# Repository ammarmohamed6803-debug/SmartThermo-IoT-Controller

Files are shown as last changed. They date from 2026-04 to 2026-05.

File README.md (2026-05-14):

# SmartThermo: IoT Environmental Controller 🌡️⚙️

An automated, closed-loop climate regulation and telemetry logging system built with an ESP32. This project reverse-engineers stateful AC IR protocols to maintain strict temperature tolerances while logging real-time data to the cloud.

## Features
* **Real-Time Edge Sensing:** Uses a DHT22 sensor for high-fidelity temperature and humidity tracking.
* **Algorithmic IR Control:** Generates mathematical 64-bit Gree/Sharp IR protocols on the fly to eliminate signal jitter and reliably control the AC unit.
* **Closed-Loop Actuation:** Automatically adjusts the AC state to maintain a strict ±0.5°C tolerance of the user's setpoint.
* **Cloud Telemetry Logging:** Connects via Wi-Fi to POST JSON payload data (Temp, Hum, AC State, Setpoint) to a custom Google Apps Script webhook, logging chronologically in Google Sheets.
* **Tactile HMI & Alerts:** Features an I2C LCD for live telemetry, manual override buttons, and a non-blocking audiovisual alarm system for out-of-range states.

## Hardware Components
* ESP32 Development Board
* DHT22 Temperature & Humidity Sensor
* 38kHz IR Transmitter LED (driven by 2N2222 NPN Transistor)
* 16x2 I2C LCD Display
* Active Buzzer & Status LEDs (Red/Green)
* Tactile Push Buttons

## System Architecture 


## Circuit Schematic


## 3D Enclosure Design


## Libraries Used
* `IRremoteESP8266` (For Gree/TECO/Haier protocol generation)
* `DHT sensor library`
* `LiquidCrystal_I2C`
* `WiFi.h` & `HTTPClient.h`

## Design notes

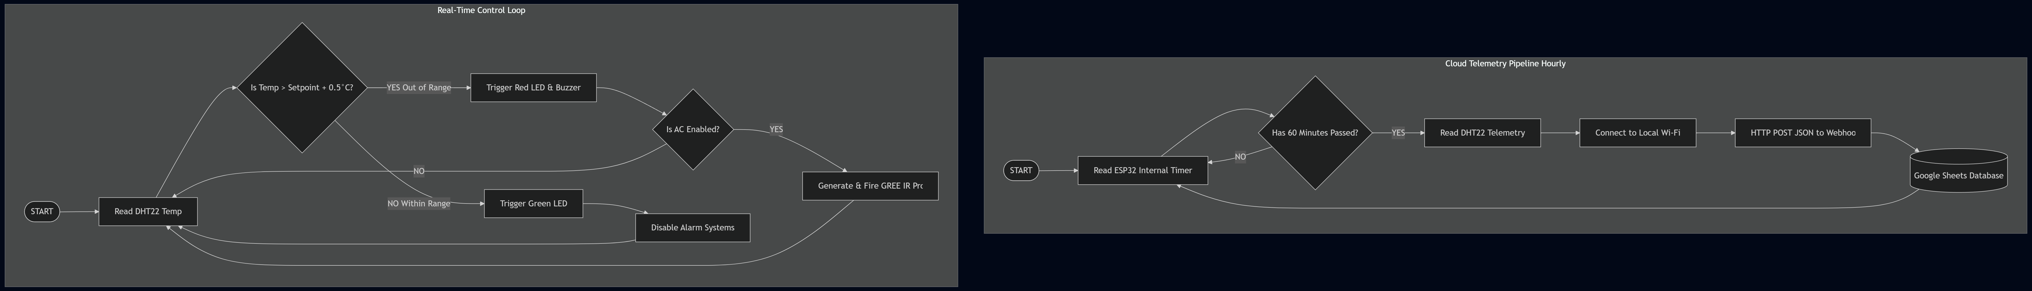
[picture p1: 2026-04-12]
flowchart.png

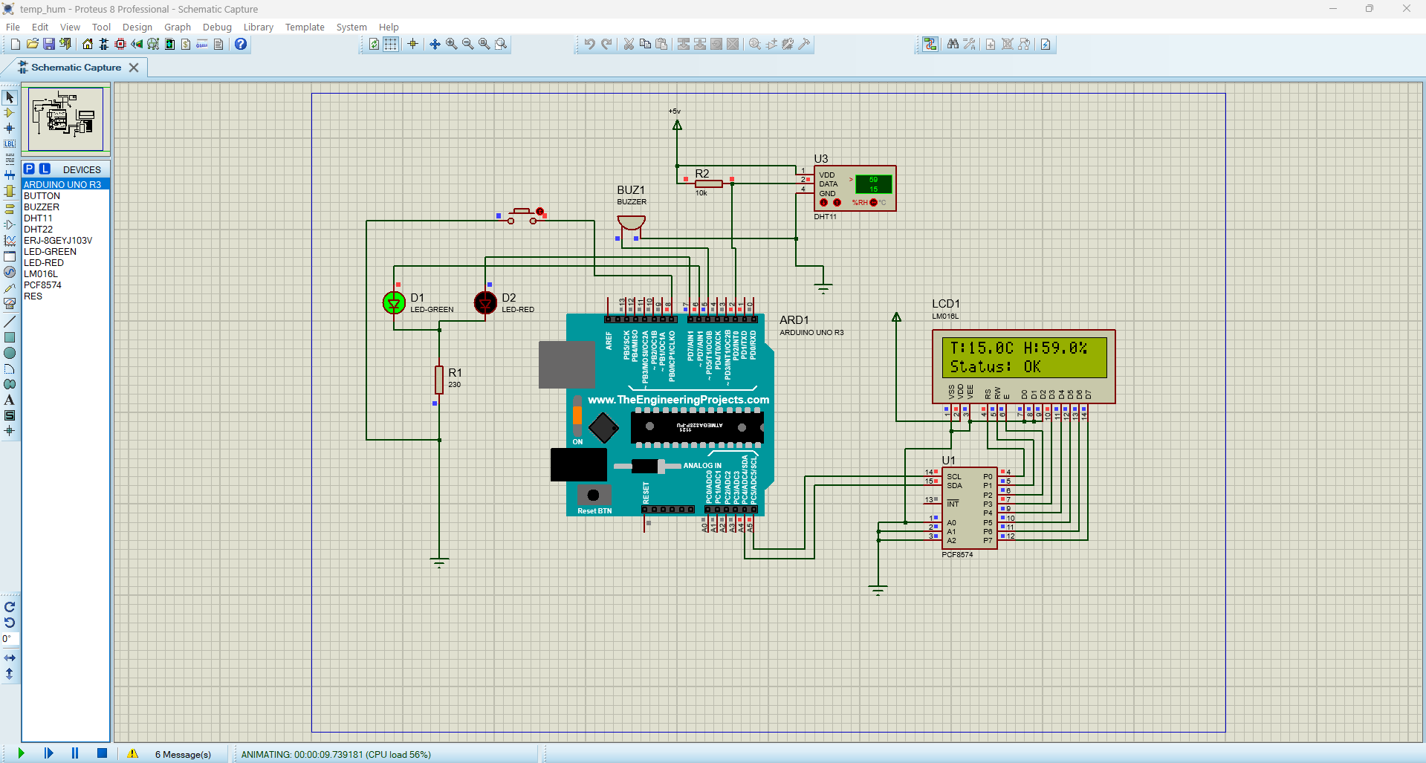
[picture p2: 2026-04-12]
basic circuit.png

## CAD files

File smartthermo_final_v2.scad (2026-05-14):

// ============================================================
//  SmartThermo Enclosure — FINAL v2
//  For: ESP32 + 16x2 LCD I2C + DHT22-MOD + IR LED + LEDs
//       + Buzzer + 3 Buttons + 400pt Breadboard + Jumper Wires
// ============================================================
//  Print settings: 0.2mm layer, 20% infill, no supports needed
//  Material: PLA or PETG
// ============================================================
//  v2 fixes:
//    - USB hole: fixed translate Y (was not reaching inner face)
//    - Wall mount keyholes: same fix + repositioned near top
//    - keyhole_slot depth increased to wall+4 (cuts fully through)
//    - Box + Lid combined in ONE STL file
// ============================================================

/* [Main Dimensions] */
wall        = 2.5;
corner_r    = 3;

inner_w     = 100;
inner_d     = 90;
inner_h     = 70;

outer_w     = inner_w + 2*wall;   // 105mm
outer_d     = inner_d + 2*wall;   // 95mm
outer_h     = inner_h + 2*wall;   // 75mm

/* [LCD Cutout — 16x2 I2C] */
lcd_view_w  = 65;
lcd_view_h  = 15;
lcd_pcb_w   = 80;
lcd_pcb_h   = 36;
lcd_x       = 0;
lcd_z       = 12;

/* [Buttons — 6mm panel-mount, 7mm holes] */
btn_dia     = 7;
btn_spacing = 14;
btn_x_start = 10;
btn_z_pos   = -20;

/* [LEDs — 5mm] */
led_dia     = 5.2;
led_spacing = 10;
led_x_off   = -20;
led_z_off   = -20;

/* [IR LED] */
ir_dia      = 5.2;
ir_x        = -38;
ir_z        = -20;

/* [DHT22 — through-hole, insert from inside] */
dht_cut_w   = 20;
dht_cut_h   = 25;
dht_z_off   = 5;

/* [Buzzer — on LID] */
buzz_dia    = 2.0;
buzz_count  = 7;
buzz_r      = 6;
buzz_x      = 25;
buzz_y      = 10;

/* [USB — back face] */
usb_w       = 14;
usb_h       = 8;
usb_z       = -25;

/* [Mounting Posts] */
post_hole   = 2.5;

/* [Lid] */
lid_h       = 2.5;

/* [Wall Mount — keyhole slots on back, near top] */
mount_slot_w  = 8;
mount_slot_h  = 14;
mount_spacing = 60;
// Near top of back face so box hangs below the screws
mount_z       = outer_h - lid_h - 18;   // ~54mm from bottom

// ── Helper: rounded box ──────────────────────────────────
module rounded_box(w, d, h, r) {
    hull() {
        for (x = [-w/2+r, w/2-r])
            for (y = [-d/2+r, d/2-r])
                translate([x, y, 0])
                    cylinder(h=h, r=r, $fn=40);
    }
}

// ── Rounded slot helper ──────────────────────────────────
module rounded_slot(w, h, depth) {
    hull() {
        for (y = [-h/2 + w/2, h/2 - w/2])
            translate([0, y, 0])
                cylinder(d=w, h=depth, $fn=20);
    }
}

// ── Rounded rectangular cutout ───────────────────────────
module rounded_lcd_cutout(w, h, depth) {
    r = 1.5;
    hull() {
        for (x = [-w/2+r, w/2-r])
            for (y = [-h/2+r, h/2-r])
                translate([x, y, 0])
                    cylinder(r=r, h=depth, $fn=20);
    }
}

// ── Keyhole wall mount slot ──────────────────────────────
// depth = wall+4 so it cuts fully from inner to outer face
module keyhole_slot(depth) {
    // Large circle at top — screw HEAD passes through to hang
    translate([0, mount_slot_h/2 - mount_slot_w/2, 0])
        cylinder(d=mount_slot_w, h=depth, $fn=30);
    // Vertical slot — box slides DOWN onto screw shaft
    translate([-mount_slot_w/4, -mount_slot_h/2, 0])
        cube([mount_slot_w/2, mount_slot_h, depth]);
    // Small circle at bottom — grips screw shaft snugly
    translate([0, -mount_slot_h/2, 0])
        cylinder(d=mount_slot_w/2, h=depth, $fn=20);
}

// ── MAIN BOX ─────────────────────────────────────────────
module main_box() {
    difference() {

        // Outer shell
        rounded_box(outer_w, outer_d, outer_h - lid_h, corner_r);

        // Inner cavity
        translate([0, 0, wall])
            rounded_box(inner_w, inner_d, outer_h, corner_r - wall/2);

        // ════════════════════════════════════════════════
        // FRONT FACE cutouts
        // ════════════════════════════════════════════════

        // LCD viewing window
        translate([lcd_x, -outer_d/2 - 1, outer_h/2 + lcd_z])
            rotate([-90, 0, 0])
                rounded_lcd_cutout(lcd_view_w, lcd_view_h, wall + 2);

        // LCD PCB slot (recessed from inside)
        translate([lcd_x, -outer_d/2 + wall - 1, outer_h/2 + lcd_z])
            rotate([-90, 0, 0])
                rounded_lcd_cutout(lcd_pcb_w + 1, lcd_pcb_h + 1, 2);

        // Green LED hole
        translate([led_x_off - led_spacing/2, -outer_d/2 - 1, outer_h/2 + led_z_off])
            rotate([-90, 0, 0])
                cylinder(d=led_dia, h=wall+2, $fn=30);

        // Red LED hole
        translate([led_x_off + led_spacing/2, -outer_d/2 - 1, outer_h/2 + led_z_off])
            rotate([-90, 0, 0])
                cylinder(d=led_dia, h=wall+2, $fn=30);

        // LED label indents
        translate([led_x_off - led_spacing/2, -outer_d/2 - 0.1, outer_h/2 + led_z_off + 6])
            rotate([-90, 0, 0])
                cylinder(d=2, h=0.8, $fn=20);
        translate([led_x_off + led_spacing/2, -outer_d/2 - 0.1, outer_h/2 + led_z_off + 6])
            rotate([-90, 0, 0])
                cylinder(d=2, h=0.8, $fn=20);

        // IR LED hole + cone
        translate([ir_x, -outer_d/2 - 1, outer_h/2 + ir_z])
            rotate([-90, 0, 0])
                cylinder(d=ir_dia, h=wall+2, $fn=30);
        translate([ir_x, -outer_d/2 - 0.1, outer_h/2 + ir_z])
            rotate([-90, 0, 0])
                cylinder(d1=ir_dia, d2=ir_dia+3, h=wall+0.2, $fn=30);

        // Button holes — 7mm for 6mm panel-mount buttons
        for (i = [0, 1, 2]) {
            translate([btn_x_start + i * btn_spacing, -outer_d/2 - 1, outer_h/2 + btn_z_pos])
                rotate([-90, 0, 0])
                    cylinder(d=btn_dia, h=wall+2, $fn=30);
        }

        // Button labels: DN / PWR / UP
        translate([btn_x_start, -outer_d/2 - 0.1, outer_h/2 + btn_z_pos + 7])
            rotate([90, 0, 0]) linear_extrude(0.8)
                text("DN", size=3, halign="center", valign="center",
                     font="Liberation Sans:style=Bold");
        translate([btn_x_start + btn_spacing, -outer_d/2 - 0.1, outer_h/2 + btn_z_pos + 7])
            rotate([90, 0, 0]) linear_extrude(0.8)
                text("PWR", size=2.5, halign="center", valign="center",
                     font="Liberation Sans:style=Bold");
        translate([btn_x_start + 2*btn_spacing, -outer_d/2 - 0.1, outer_h/2 + btn_z_pos + 7])
            rotate([90, 0, 0]) linear_extrude(0.8)
                text("UP", size=3, halign="center", valign="center",
                     font="Liberation Sans:style=Bold");

        // ════════════════════════════════════════════════
        // RIGHT SIDE — DHT22 through-hole
        // Starts 1mm before inner wall → cuts fully through
        // ════════════════════════════════════════════════
        translate([inner_w/2 - 1, 0, outer_h/2 + dht_z_off])
            rotate([0, 90, 0])
                rounded_lcd_cutout(dht_cut_w, dht_cut_h, wall + 4);

        // ════════════════════════════════════════════════
        // BACK FACE — USB port
        // FIXED: translate Y = inner_d/2 - 1 (starts before inner face)
        //        depth = wall + 4  (cuts fully through to outside)
        // ════════════════════════════════════════════════
        translate([0, inner_d/2 - 1, outer_h/2 + usb_z])
            rotate([90, 0, 0])
                rounded_slot(usb_w, usb_h, wall + 4);

        // ════════════════════════════════════════════════
        // BACK FACE — Wall mount keyhole slots
        // FIXED: translate Y = inner_d/2 - 1 (starts before inner face)
        //        depth = wall + 4 passed into module
        //        mount_z near top of box for proper wall hang
        // ════════════════════════════════════════════════
        for (x = [-mount_spacing/2, mount_spacing/2])
            translate([x, inner_d/2 - 1, mount_z])
                rotate([90, 0, 0])
                    keyhole_slot(wall + 4);

        // ════════════════════════════════════════════════
        // BOTTOM — ventilation slots
        // ════════════════════════════════════════════════
        for (i = [-3:3]) {
            translate([i * 12, 0, -1])
                rounded_slot(3, 40, wall + 2);
        }
    }

    // ── Screw posts for lid ──────────────────────────────
    screw_inset = 6;
    for (x = [-inner_w/2 + screw_inset, inner_w/2 - screw_inset])
        for (y = [-inner_d/2 + screw_inset, inner_d/2 - screw_inset])
            translate([x, y, wall])
                difference() {
                    cylinder(d=6, h=outer_h - lid_h - wall, $fn=30);
                    translate([0, 0, outer_h - lid_h - wall - 8])
                        cylinder(d=post_hole, h=10, $fn=20);
                }
}

// ── LID ──────────────────────────────────────────────────
module lid() {
    difference() {
        rounded_box(outer_w, outer_d, lid_h, corner_r);
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

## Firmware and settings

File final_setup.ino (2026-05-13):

/*
 * ============================================================
 * SmartThermo Phase 4 — 3-button final
 * ESP32 + DHT22 + Gree AC (IR) + I2C LCD + Wi-Fi Logging
 * ============================================================
 * v4.2 changes:
 *   - FIXED: IR transmission now suspends log task during send
 *           (prevents Wi-Fi/FreeRTOS timing disruption)
 *   - Reverted to single IR send (double-send was unreliable)
 *   - 3 buttons: UP, DOWN, POWER
 *   - UP/DOWN auto-sends new setpoint after 2s wait
 *   - UP long-press (2s) toggles MANUAL / AUTO mode
 *   - POWER toggles AC ON/OFF
 *   - Alarm fires when OUT of range
 *   - HTTP logging on Core 0 (non-blocking)
 * ============================================================
 * MODE 1: Manual — UP/DOWN sets AC temp directly
 * MODE 2: Auto  — UP/DOWN sets target ROOM temp
 * ──────────────────────────────────────────────────────────────
 * UP short      : setpoint +1  (auto-sends after 2s if AC on)
 * UP long (2s)  : toggle MANUAL / AUTO mode
 * DOWN short    : setpoint -1  (auto-sends after 2s if AC on)
 * POWER short   : toggle AC ON / OFF
 * ============================================================
 * >>>  CHANGE roomName PER UNIT BEFORE UPLOADING  
 * ============================================================
 */

#include <Arduino.h>
#include <Wire.h>
#include <LiquidCrystal_I2C.h>
#include <IRremoteESP8266.h>
#include <ir_Gree.h>
#include <DHT.h>
#include <WiFi.h>
#include <HTTPClient.h>
#include "soc/soc.h"
#include "soc/rtc_cntl_reg.h"

// ══════════════════════════════════════════════════════════════
//  CHANGE THIS PER ROOM — must match the Google Sheet tab name
// ══════════════════════════════════════════════════════════════
const char* roomName = "Filling Room";

// ── Wi-Fi & Google Sheets config ─────────────────────────────
const char* ssid      = "SparkeLabs_2.4GHz";
const char* password  = "12345678";
const char* scriptUrl = "https://script.google.com/macros/s/AKfycby3Sph_hCZV9bX5cS6v5fkehoYulXwKRZOLm6wEMfRHKZ4dpHyjm0AnLq1JRopFkwZ4/exec";

// ── Pin config ───────────────────────────────────────────────
#define IR_LED_PIN      4
#define DHT_PIN         14
#define BTN_UP_PIN      12
#define BTN_DOWN_PIN    32
#define BTN_POWER_PIN   33
#define RED_LED_PIN     25
#define GREEN_LED_PIN   26
#define BUZZER_PIN      27

// ── Settings ─────────────────────────────────────────────────
#define TEMP_MIN        16
#define TEMP_MAX        30
#define TEMP_DEFAULT    21
#define AUTO_OFFSET     2

// ── Alarm range (OUT of these = alarm) ───────────────────────
#define ALARM_TEMP_LOW   18.0
#define ALARM_TEMP_HIGH  30.0
#define ALARM_HUM_LOW    30.0
#define ALARM_HUM_HIGH   90.0

// ── Timing ───────────────────────────────────────────────────
#define DHT_INTERVAL_MS       2000
#define LONG_PRESS_MS         2000
#define BUZZER_ON_MS          150
#define BUZZER_OFF_MS         150
#define LOG_INTERVAL_MS       3600000UL
#define AUTO_RESEND_MS        900000UL
#define LOG_DEFER_MS          5000
#define DEBOUNCE_MS           50
#define SETPOINT_SEND_DELAY   2000

// ── Modes ────────────────────────────────────────────────────
#define MODE_MANUAL  0
#define MODE_AUTO    1

// ── Objects ──────────────────────────────────────────────────
DHT dht(DHT_PIN, DHT22);
LiquidCrystal_I2C lcd(0x27, 16, 2);
IRGreeAC ac(IR_LED_PIN);

// ── State ────────────────────────────────────────────────────
float currentTemp     = 0.0;
float currentHumidity = 0.0;
bool  sensorReady     = false;
bool  acOn            = false;
bool  alertActive     = false;
bool  buzzerState     = false;
int   setpoint        = TEMP_DEFAULT;
int   currentMode     = MODE_MANUAL;

unsigned long lastAutoSend = 0;
bool autoHasSentOnce = false;

TaskHandle_t   logTaskHandle = NULL;
volatile bool  logRequested  = false;
bool pendingLog = false;

bool pendingSetpointSend = false;
unsigned long lastSetpointChange = 0;

// ── Timing Variables ─────────────────────────────────────────
unsigned long lastDHTRead         = 0;
unsigned long lastBuzzerTime      = 0;
unsigned long lastLogTime         = 0;
unsigned long lastInteractionTime = 0;

// ── Button state ─────────────────────────────────────────────
bool lastUpState    = HIGH;
bool lastDownState  = HIGH;
bool lastPowerState = HIGH;
unsigned long upPressTime = 0;
bool upHeld = false;

unsigned long lastUpDebounce    = 0;
unsigned long lastDownDebounce  = 0;
unsigned long lastPowerDebounce = 0;

// ── HTTP runs on Core 0 (non-blocking) ───────────────────────
void logTask(void *parameter) {
  for (;;) {
    if (logRequested) {
      logRequested = false;

      if (WiFi.status() == WL_CONNECTED && sensorReady) {
        Serial.println("[WIFI] Connecting to Google...");
        HTTPClient http;
        http.begin(scriptUrl);
        http.addHeader("Content-Type", "application/json");
        http.setTimeout(5000);

        String modeStr = (currentMode == MODE_AUTO) ? "AUTO" : "MANUAL";
        String payload = "{\"room\":\"" + String(roomName) + "\"" +
                         ",\"temp\":" + String(currentTemp, 1) +
                         ",\"hum\":" + String(currentHumidity, 1) +
                         ",\"acState\":\"" + (acOn ? "ON" : "OFF") + "\"" +
                         ",\"setpoint\":" + String(setpoint) +
                         ",\"mode\":\"" + modeStr + "\"}";

        Serial.println("[WIFI] Sending: " + payload);
        int httpResponseCode = http.POST(payload);

        if (httpResponseCode > 0) {
          Serial.print("[WIFI] Success! HTTP Code: ");
          Serial.println(httpResponseCode);
        } else {
          Serial.print("[WIFI] Error sending POST: ");
          Serial.println(httpResponseCode);
        }
        http.end();
      } else if (WiFi.status() != WL_CONNECTED) {
        Serial.println("[WIFI] Not connected. Skipping log.");
      }
    }
    vTaskDelay(100 / portTICK_PERIOD_MS);
  }
}

// ── IR Helper Functions ──────────────────────────────────────
// FIX: suspend log task during IR send to prevent timing disruption.
// FreeRTOS + Wi-Fi can interfere with the 38kHz IR carrier.
void sendACCommand(int acTemp) {
  if (acTemp < TEMP_MIN) acTemp = TEMP_MIN;
  if (acTemp > TEMP_MAX) acTemp = TEMP_MAX;

  // Pause the log task so HTTP/Wi-Fi doesn't disrupt IR timing
  if (logTaskHandle != NULL) vTaskSuspend(logTaskHandle);
  noInterrupts();   // protect IR carrier timing

  ac.setPower(true);
  ac.setMode(kGreeCool);
  ac.setFan(kGreeFanAuto);
  ac.setTemp(acTemp);
  ac.send();

  interrupts();
  if (logTaskHandle != NULL) vTaskResume(logTaskHandle);

  Serial.print("[IR] AC ON -> ");
  Serial.print(acTemp);
  Serial.println("C");
}

void sendACOff() {
  if (logTaskHandle != NULL) vTaskSuspend(logTaskHandle);
  noInterrupts();

  ac.setPower(false);
  ac.send();

  interrupts();
  if (logTaskHandle != NULL) vTaskResume(logTaskHandle);

  Serial.println("[IR] AC OFF");
}

// ── LCD update ───────────────────────────────────────────────
void updateLCD() {
  lcd.clear();

  lcd.setCursor(0, 0);
  if (sensorReady) {
    lcd.print("T:");
    lcd.print(currentTemp, 1);
    lcd.print("C H:");
    lcd.print((int)currentHumidity);
    lcd.print("%");
  } else {
    lcd.print("T:---  H:---");
  }

  lcd.setCursor(0, 1);
  if (currentMode == MODE_MANUAL) {
    if (acOn) {
      lcd.print("AC:ON S:");
      lcd.print(setpoint);
      lcd.print("C");
    } else {
      lcd.print("AC:OFF S:");
      lcd.print(setpoint);
      lcd.print("C");
    }
  } else {
    if (acOn) {
      lcd.print("AUTO T:");
      lcd.print(setpoint);
      lcd.print("C [ON]");
    } else {
      lcd.print("AUTO T:");
      lcd.print(setpoint);
      lcd.print("C[OFF]");
    }
  }
}

// ── Alert indicators ─────────────────────────────────────────
void updateAlert(bool active) {
  alertActive = active;
  if (!active) {
    digitalWrite(GREEN_LED_PIN, HIGH);
    digitalWrite(RED_LED_PIN,   LOW);
    digitalWrite(BUZZER_PIN,    LOW);
    buzzerState = false;
  } else {
    digitalWrite(GREEN_LED_PIN, LOW);
    digitalWrite(RED_LED_PIN,   HIGH);
  }
}

// ── Buzzer non-blocking blink ────────────────────────────────
void handleBuzzer() {
  if (!alertActive) return;
  unsigned long now = millis();
  if (buzzerState && now - lastBuzzerTime >= BUZZER_ON_MS) {
    buzzerState = false;
    digitalWrite(BUZZER_PIN, LOW);
    lastBuzzerTime = now;
  } else if (!buzzerState && now - lastBuzzerTime >= BUZZER_OFF_MS) {
    buzzerState = true;
    digitalWrite(BUZZER_PIN, HIGH);
    lastBuzzerTime = now;
  }
}

// ── Beep helpers ─────────────────────────────────────────────
void buttonBeep() {
  if (alertActive) return;
  digitalWrite(BUZZER_PIN, HIGH);
  delay(40);
  digitalWrite(BUZZER_PIN, LOW);
}

void powerOnBeep() {
  if (alertActive) return;
  digitalWrite(BUZZER_PIN, HIGH); delay(60); digitalWrite(BUZZER_PIN, LOW);
  delay(60);
  digitalWrite(BUZZER_PIN, HIGH); delay(60); digitalWrite(BUZZER_PIN, LOW);
}

void powerOffBeep() {
  if (alertActive) return;
  digitalWrite(BUZZER_PIN, HIGH);
  delay(200);
  digitalWrite(BUZZER_PIN, LOW);
}

// ── Flag a log event securely ────────────────────────────────
void triggerLog() {
  pendingLog = true;
  lastInteractionTime = millis();
}

// ── Mode toggle ──────────────────────────────────────────────
void toggleMode() {
  if (currentMode == MODE_MANUAL) {
    currentMode = MODE_AUTO;
    autoHasSentOnce = false;
    lastAutoSend = 0;
    Serial.println("[MODE] -> AUTO");
  } else {
    currentMode = MODE_MANUAL;
    Serial.println("[MODE] -> MANUAL");
  }

  buttonBeep();
  delay(60);
  buttonBeep();

  updateLCD();
  triggerLog();
}

// ── Auto switch to manual when target reached ────────────────
void autoSwitchToManual() {
  currentMode = MODE_MANUAL;
  Serial.print("[MODE] Target reached -> MANUAL at ");
  Serial.print(setpoint);
  Serial.println("C");

  buttonBeep();
  delay(50);
  buttonBeep();
  delay(50);
  buttonBeep();

  updateLCD();
  triggerLog();
}

// ── Button handlers ──────────────────────────────────────────
void handleButtons() {
  bool upState    = digitalRead(BTN_UP_PIN);
  bool downState  = digitalRead(BTN_DOWN_PIN);
  bool powerState = digitalRead(BTN_POWER_PIN);
  unsigned long now = millis();

  // ════════════════════════════════════════════════════════════
  // BTN UP — short: setpoint+1 / long (2s): toggle Manual/Auto
  // ════════════════════════════════════════════════════════════
  if (lastUpState == HIGH && upState == LOW && (now - lastUpDebounce > DEBOUNCE_MS)) {
    lastUpDebounce = now;
    upPressTime = now;
    upHeld = false;
    lastInteractionTime = now;
    buttonBeep();
  }

  if (upState == LOW && !upHeld) {
    if (now - upPressTime >= LONG_PRESS_MS) {
      upHeld = true;
      toggleMode();
    }
  }

  if (lastUpState == LOW && upState == HIGH) {
    if (!upHeld) {
      if (setpoint < TEMP_MAX) {
        setpoint++;
        Serial.print("[BTN] Setpoint: ");
        Serial.println(setpoint);

        if (acOn) {
          pendingSetpointSend = true;
          lastSetpointChange = now;
        }
        if (currentMode == MODE_AUTO) {
          autoHasSentOnce = false;
          lastAutoSend = 0;
        }
        updateLCD();
      }
    }
    upHeld = false;
  }
  lastUpState = upState;

  // ════════════════════════════════════════════════════════════
  // BTN DOWN — setpoint-1
  // ════════════════════════════════════════════════════════════
  if (lastDownState == HIGH && downState == LOW && (now - lastDownDebounce > DEBOUNCE_MS)) {
    lastDownDebounce = now;
    lastInteractionTime = now;
    buttonBeep();
    if (setpoint > TEMP_MIN) {
      setpoint--;
      Serial.print("[BTN] Setpoint: ");
      Serial.println(setpoint);

      if (acOn) {
        pendingSetpointSend = true;
        lastSetpointChange = now;
      }
      if (currentMode == MODE_AUTO) {
        autoHasSentOnce = false;
        lastAutoSend = 0;
      }
      updateLCD();
    }
  }
  lastDownState = downState;

  // ════════════════════════════════════════════════════════════
  // BTN POWER — toggle AC ON/OFF
  // ════════════════════════════════════════════════════════════
  if (lastPowerState == HIGH && powerState == LOW && (now - lastPowerDebounce > DEBOUNCE_MS)) {
    lastPowerDebounce = now;
    lastInteractionTime = now;
  }

  if (lastPowerState == LOW && powerState == HIGH) {
    if (!acOn) {
      acOn = true;
      if (currentMode == MODE_MANUAL) {
        Serial.print("[PWR] AC ON manual -> ");
        Serial.println(setpoint);
        sendACCommand(setpoint);
      } else {
        int acTemp = setpoint - AUTO_OFFSET;
        Serial.print("[PWR] AC ON auto -> ");
        Serial.println(acTemp);
        sendACCommand(acTemp);
        lastAutoSend = now;
        autoHasSentOnce = true;
      }
      powerOnBeep();
    } else {
      acOn = false;
      autoHasSentOnce = false;
      pendingSetpointSend = false;
      Serial.println("[PWR] AC OFF");
      sendACOff();
      powerOffBeep();
    }
    updateLCD();
    triggerLog();
  }
  lastPowerState = powerState;
}

// ── DHT read + auto-control ──────────────────────────────────
void readDHT() {
  if (millis() - lastDHTRead < DHT_INTERVAL_MS) return;
  lastDHTRead = millis();

  float t = dht.readTemperature();
  float h = dht.readHumidity();

  if (isnan(t) || isnan(h)) {
    Serial.println("[DHT] Read failed, retrying...");
    return;
  }

  currentTemp     = t;
  currentHumidity = h;
  sensorReady     = true;

  bool outOfRange = (t <= ALARM_TEMP_LOW) || (t >= ALARM_TEMP_HIGH) ||
                    (h <= ALARM_HUM_LOW)  || (h >= ALARM_HUM_HIGH);
  updateAlert(outOfRange);

  if (currentMode == MODE_AUTO && acOn) {
    unsigned long now = millis();

    if (t <= setpoint + 0.5f && autoHasSentOnce) {
      autoSwitchToManual();
      return;
    }

    bool canResend = !autoHasSentOnce || (now - lastAutoSend >= AUTO_RESEND_MS);

    if (t > setpoint + 0.5f && canResend) {
      int acTemp = setpoint - AUTO_OFFSET;
      Serial.print("[AUTO] Room ");
      Serial.print(t, 1);
      Serial.print("C > target ");
      Serial.print(setpoint);
      Serial.print("C, sending AC=");
      Serial.print(acTemp);
      Serial.println("C");
      sendACCommand(acTemp);
      lastAutoSend = now;
      autoHasSentOnce = true;
      triggerLog();
    }
  }

  updateLCD();
}

// ── Setup ────────────────────────────────────────────────────
void setup() {
  WRITE_PERI_REG(RTC_CNTL_BROWN_OUT_REG, 0);
  Serial.begin(115200);

  pinMode(BTN_UP_PIN,    INPUT_PULLUP);
  pinMode(BTN_DOWN_PIN,  INPUT_PULLUP);
  pinMode(BTN_POWER_PIN, INPUT_PULLUP);
  pinMode(RED_LED_PIN,   OUTPUT);
  pinMode(GREEN_LED_PIN, OUTPUT);
  pinMode(BUZZER_PIN,    OUTPUT);

  digitalWrite(GREEN_LED_PIN, HIGH);
  digitalWrite(RED_LED_PIN,   LOW);
  digitalWrite(BUZZER_PIN,    LOW);

  lcd.init();
  lcd.backlight();
  lcd.setCursor(0, 0);
  lcd.print("  SmartThermo   ");
  lcd.setCursor(0, 1);
  lcd.print("Connecting Wi-Fi");

  WiFi.begin(ssid, password);
  Serial.print("Connecting to ");
  Serial.print(ssid);

  int attempts = 0;
  while (WiFi.status() != WL_CONNECTED && attempts < 20) {
    delay(500);
    Serial.print(".");
    attempts++;
  }

  if (WiFi.status() == WL_CONNECTED) {
    Serial.println("\n[WIFI] Connected!");
    lcd.setCursor(0, 1);
    lcd.print(" Wi-Fi Connected");
  } else {
    Serial.println("\n[WIFI] Failed to connect.");
    lcd.setCursor(0, 1);
    lcd.print(" Wi-Fi Failed   ");
  }

  delay(2000);

  dht.begin();
  ac.begin();

  xTaskCreatePinnedToCore(
    logTask, "logTask", 8192, NULL, 1, &logTaskHandle, 0
  );

  lcd.clear();
  lcd.setCursor(0, 0);
  lcd.print("  SmartThermo   ");
  lcd.setCursor(0, 1);
  lcd.print(roomName);
  delay(1500);

  updateLCD();

  Serial.println("=========================================");
  Serial.print("  SmartThermo v4.2 Ready — ");
  Serial.println(roomName);
  Serial.println("  UP/DOWN    : adjust setpoint (auto-send 2s)");
  Serial.println("  UP long    : toggle MANUAL / AUTO mode");
  Serial.println("  POWER      : toggle AC ON / OFF");
  Serial.println("=========================================");
}

// ── Loop ─────────────────────────────────────────────────────
void loop() {
  handleButtons();
  handleBuzzer();
  readDHT();

  if (pendingSetpointSend && (millis() - lastSetpointChange >= SETPOINT_SEND_DELAY)) {
    pendingSetpointSend = false;
    if (acOn) {
      if (currentMode == MODE_MANUAL) {
        Serial.print("[DEFER] Sending setpoint: ");
        Serial.println(setpoint);
        sendACCommand(setpoint);
      } else {
        int acTemp = setpoint - AUTO_OFFSET;
        Serial.print("[DEFER] Sending auto AC: ");
        Serial.println(acTemp);
        sendACCommand(acTemp);
        lastAutoSend = millis();
        autoHasSentOnce = true;
      }
      triggerLog();
    }
  }

  if (pendingLog && (millis() - lastInteractionTime >= LOG_DEFER_MS)) {
    pendingLog = false;
    logRequested = true;
  }

  if (millis() - lastLogTime >= LOG_INTERVAL_MS) {
    lastLogTime = millis();
    logRequested = true;
  }
}
